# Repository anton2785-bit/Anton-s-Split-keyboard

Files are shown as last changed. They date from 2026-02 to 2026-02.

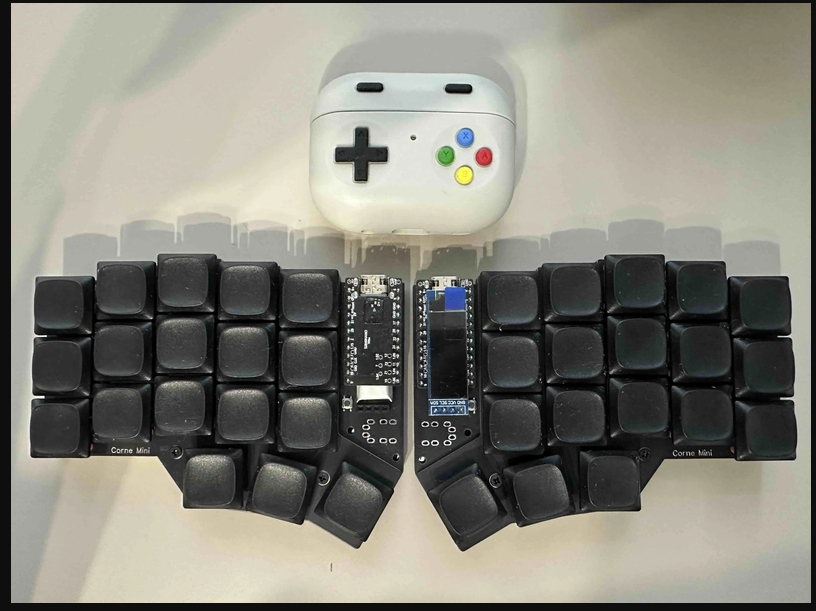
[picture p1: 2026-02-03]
Images/Inspiration image.png

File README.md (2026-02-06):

# Anton-s-Split-keyboard
---
# BOM
* 2x XIAO nRF52840 SMD ( the microcontrollers )
* 40x MX-Style switches ( preferably black or red)
* 40x Black keykaps
* 40x diodes
* 3x mini LEDs
* 2x Batteries
* 1x Rotary encoder
* The 2 difrent case parts
* The 2 PCBs
---
# Images
* This image inspired me for the layout for the keyboard
Inspiration image

* These are both sides of the keyboard in the shematic tab in kicad
Schematic PCB left side
Schematic PCB right side

* This is the final PCB wiring
PCB in PCB editor

* and the 3d models of it
3D model PCB 1
3D model PCB 2

* This is the case, that i made
3D model case

* And this is the whole assembly
3D model assembly

---
# Instructions of how to assemble
* First solder all of the diodes, keyboard switches, LEDs, Microcontrollers and batteries
* Second place the now assembled PCB in the case and connect it to a computer via USB C cable
* Third you need to upload the Firmware on the microcontrollers
* And finally you need to put all of the keycaps and test the keyboard

---
# Use Cases
- Expanding my hands-on experience with hardware by designing more advanced PCBs and practicing soldering.
- Challenging myself to improve typing speed and ergonomics by adapting to different keyboard layouts.

---
# Credits

Designed and built by (Anton/ Anton-2785-bit) Inspired by open‑source mechanical keyboard and hackpad communities (https://blueprint.hackclub.com/home).

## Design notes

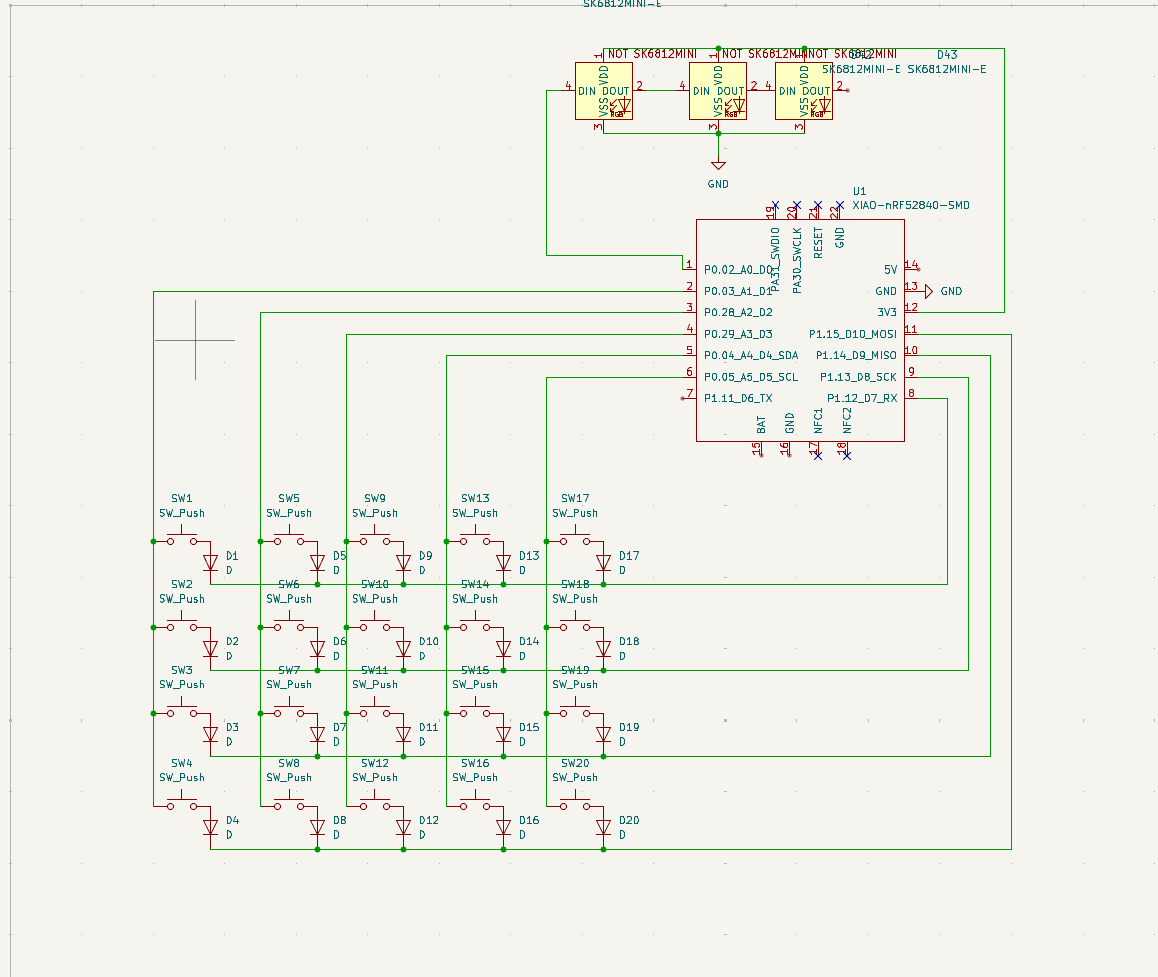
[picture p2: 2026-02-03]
Images/Schematic PCB left side.png

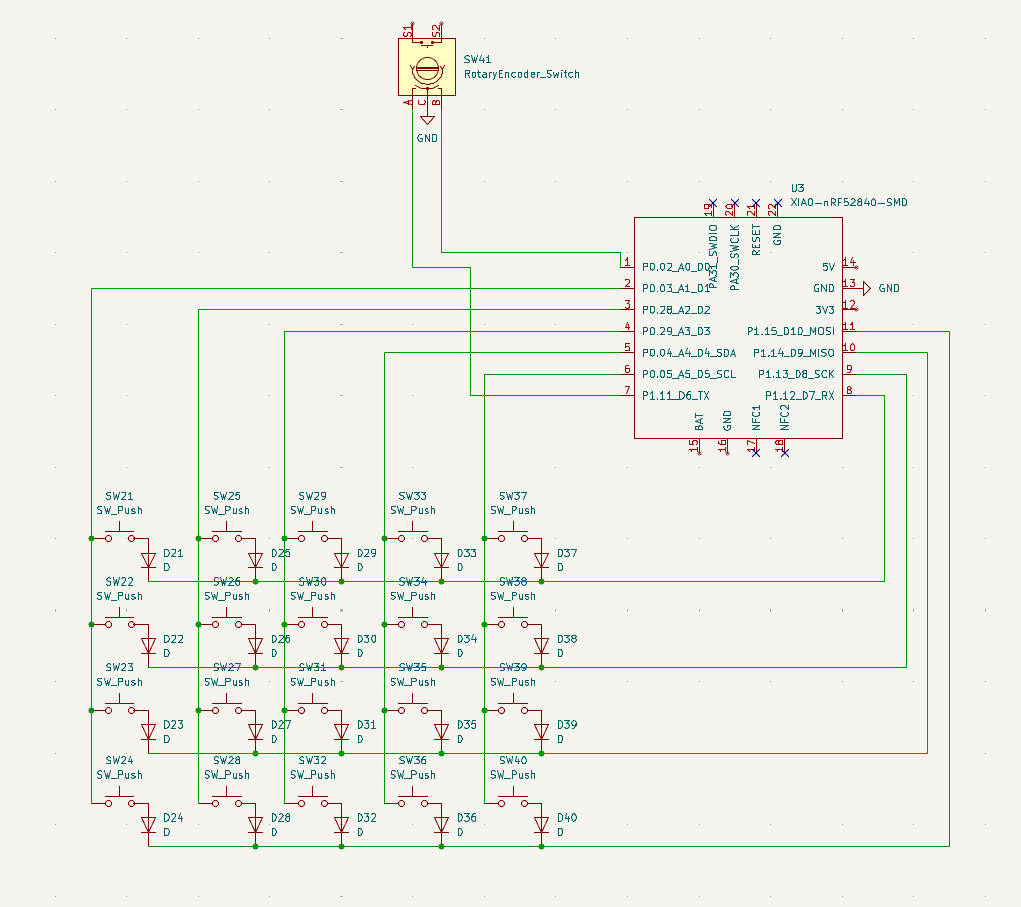
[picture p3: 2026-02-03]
Images/Schematic PCB right side.png

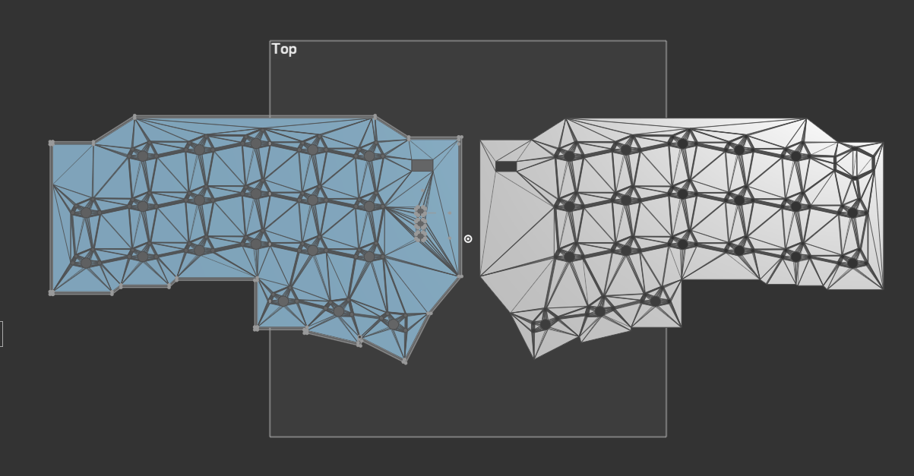
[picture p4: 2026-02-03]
Images/3D model PCB 1.png

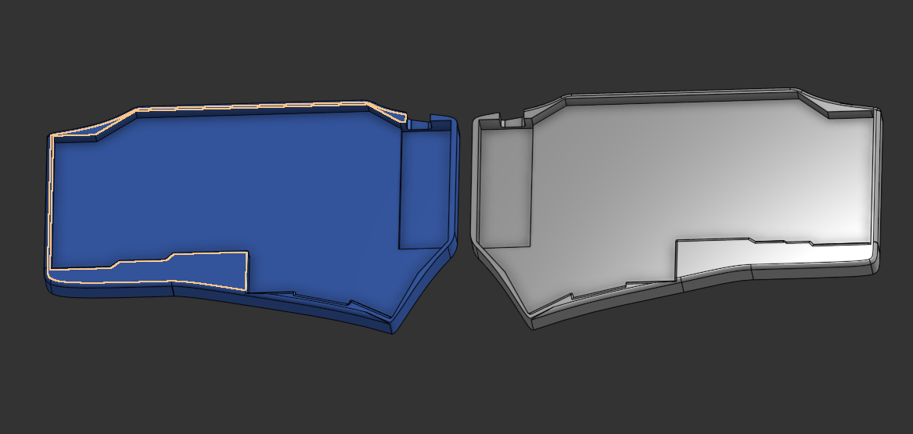
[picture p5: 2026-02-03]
Images/3D model case.png

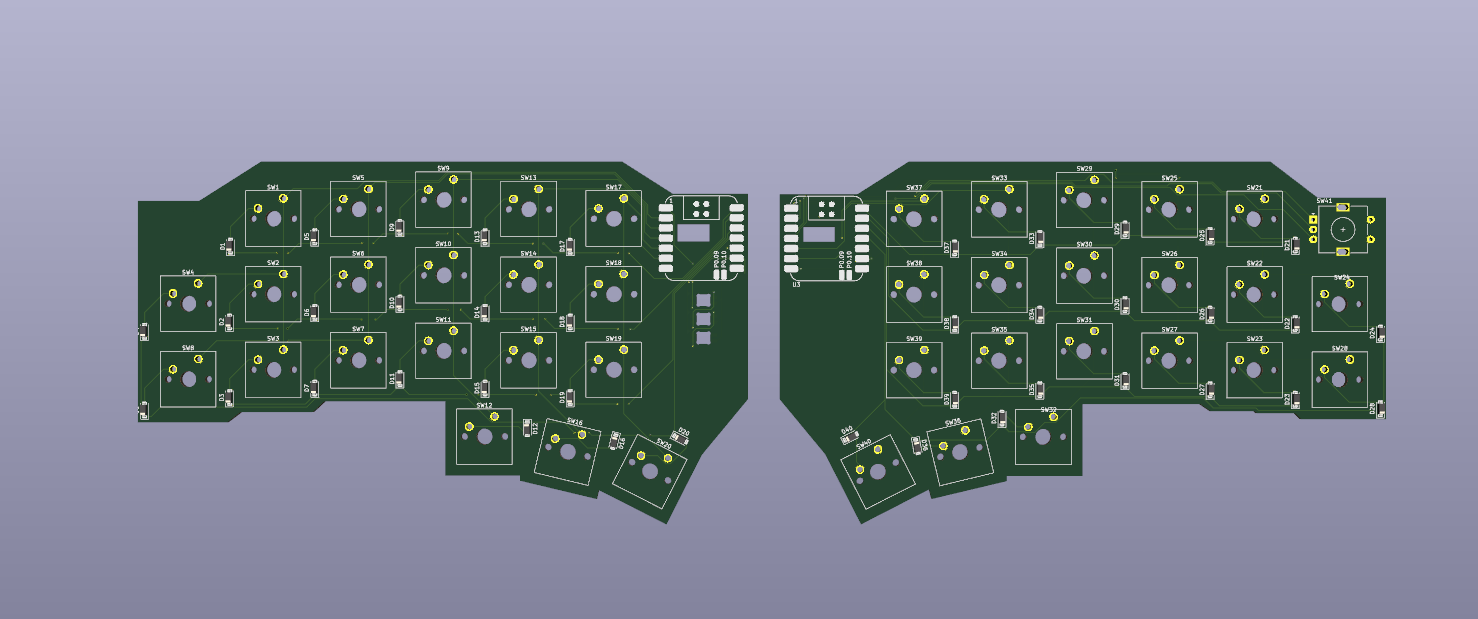
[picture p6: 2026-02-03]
Images/3D model PCB 2.png

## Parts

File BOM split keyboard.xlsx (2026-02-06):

Product name | Product description | Prodict link | Product unit needed | Product amount in listing | Product price euro | Product price USD
Seeed Studio XIAO nRF52840 | A microcontroller for each side | Seed Studio (https://www.seeedstudio.com/Seeed-XIAO-BLE-nRF52840-p-5201.html) | 2 | 2 | 17.89 | 19.80
Cherry MX Black Switch 5 Pins | Keyboard switches | Aliexpress (https://www.aliexpress.com/item/1005007588533637.html?mp=1) | 40 | 50 | 20.02 | 23.62
EC11 Encoder With Push Button | Rotary encoder for volume | Aliexpress (https://www.aliexpress.com/item/1005006111225091.html?curPageLogUid=G9LCGapRte49) | 1 | 2 | 2.74 | 3.23
3.7V 750mAh Battery | A battery for each side | Aliexpress (https://www.aliexpress.com/item/1005007138612313.html?curPageLogUid=ZzNXtTF9czc2) | 2 | 2 | 10.19 ( 0.86 with new shoppers save) | 12.03 or 1.01
Diodes 1N5819 SOD123 | Diodes | Aliexpress (https://www.aliexpress.com/item/1005010373909049.html?mp=1) | 40 | 100 | 2.13 | 2.51
SK6812 MINI-E RGB | Mini LEDs for showing layout number | Aliexpress (https://www.aliexpress.com/item/1005008591589739.html?curPageLogUid=bhxoNd0DLbsU) | 3 | 100 | 3.56 | 4.20
Blank black keycaps | Keycaps for the switches | Aliexpress (https://www.aliexpress.com/item/1005005305167568.html?mp=1) | 40 | 20 | 11.16 | 13.17
Left side PCB | The PCB for the left side | image bellow | 5 | 1 | 8.04 | 9.49
Right side PCB | The PCB for the right side | image bellow | 5 | 1 | 8.04 | 9.49
 |  |  |  |  | Price without new shopers save | 97.54
 |  |  |  |  | Price with new shopers save | 86.52
 |  |  |  |  | Shipping from aliexpress - 2.27 euro | 2.68
 |  |  |  |  | Shipping from seed studio - 8.24 euro | 9.72
 |  |  |  |  | Shipping from JLCPCB | 7

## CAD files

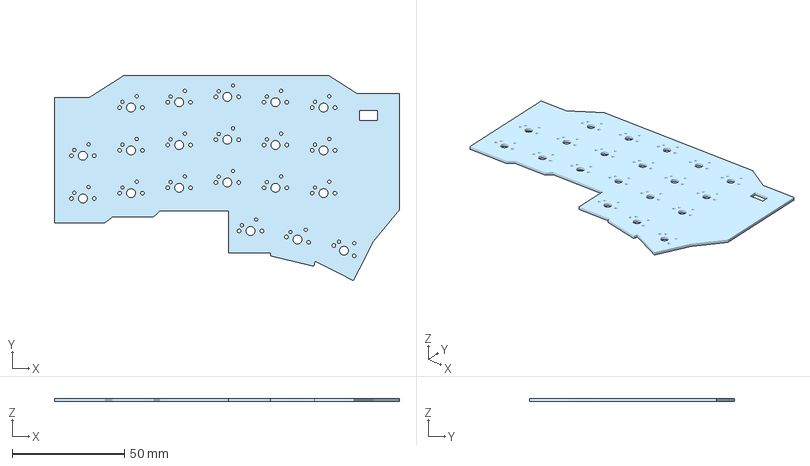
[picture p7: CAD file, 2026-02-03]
CAD/PCB left.step
153.6 x 91.4 x 1.51 mm

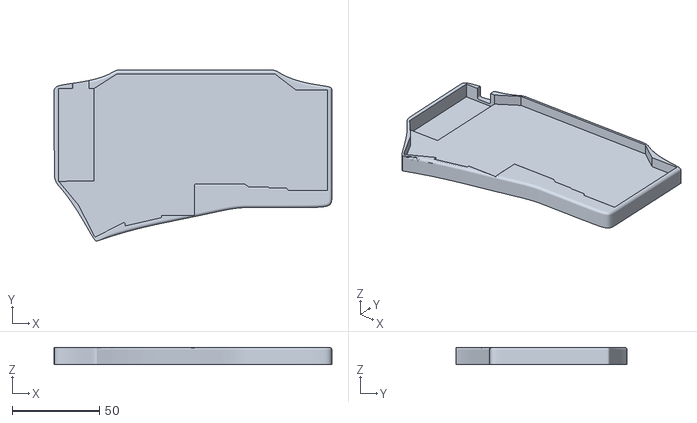
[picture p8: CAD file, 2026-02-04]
Production/Right case.stl
159.7 x 98.5 x 10.0

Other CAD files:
CAD/PCB right.step
Production/Left case.stl
CAD/Case left.step
CAD/Case right.step

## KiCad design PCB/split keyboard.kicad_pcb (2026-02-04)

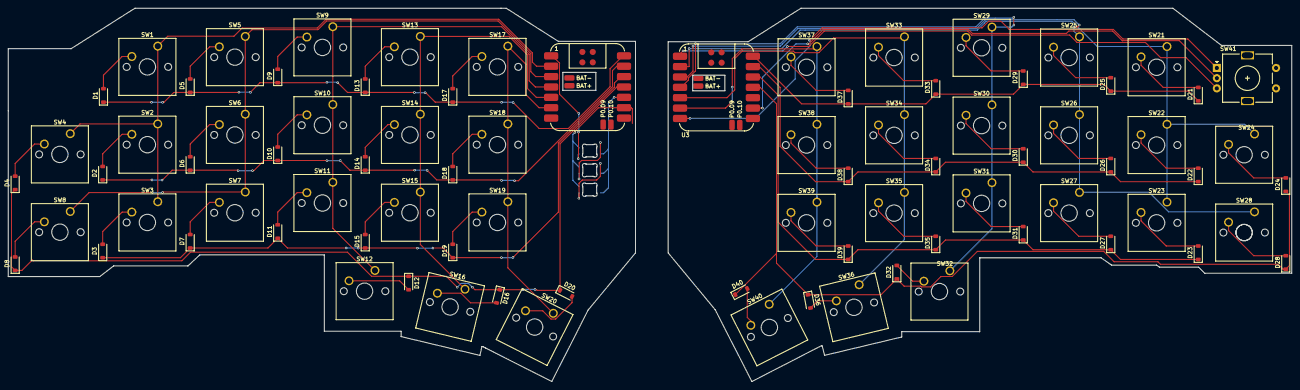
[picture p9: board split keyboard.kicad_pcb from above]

Board: 2 copper layers, 314.3 x 91.4 mm, 86 parts (0 on the bottom side), 65 nets.

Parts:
D1, D2, D3, D4, D5, D6, D7, D8, D9, D10, D11, D12, D13, D14, D15, D16, D17, D18, D19, D20, D21, D22, D23, D24, D25, D26, D27, D28, D29, D30, D31, D32, D33, D34, D35, D36, D37, D38, D39, D40: D; D_SOD-123
D41, D42, D43: SK6812MINI-E; MX_SK6812MINI-E_REV
SW1, SW2, SW3, SW4, SW5, SW6, SW7, SW8, SW9, SW10, SW11, SW12, SW13, SW14, SW15, SW16, SW17, SW18, SW19, SW20, SW21, SW22, SW23, SW24, SW25, SW26, SW27, SW28, SW29, SW30, SW31, SW32, SW33, SW34, SW35, SW36, SW37, SW38, SW39, SW40: SW_Push; SW_Cherry_MX_1.00u_PCB
SW41: RotaryEncoder_Switch; RotaryEncoder_Alps_EC11E-Switch_Vertical_H20mm
U1, U3: XIAO-nRF52840-SMD; Xiao_nRF52840_AC_Reflow

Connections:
GND: D41.3 (VSS), D42.3 (VSS), D43.3 (VSS), SW41.C, U1.13 (GND), U3.13 (GND)
unnamed: D1.2 (A), SW1.2
unnamed: D1.1 (K), D5.1 (K), D9.1 (K), D13.1 (K), D17.1 (K), U1.8 (P1.12_D7_RX)
unnamed: D2.2 (A), SW2.2
unnamed: D3.2 (A), SW3.2
unnamed: D4.2 (A), SW4.2
unnamed: D5.2 (A), SW5.2
unnamed: D6.2 (A), SW6.2
unnamed: D7.2 (A), SW7.2
unnamed: D8.2 (A), SW8.2
unnamed: D9.2 (A), SW9.2
unnamed: D10.2 (A), SW10.2
unnamed: D2.1 (K), D6.1 (K), D10.1 (K), D14.1 (K), D18.1 (K), U1.9 (P1.13_D8_SCK)
unnamed: D11.2 (A), SW11.2
unnamed: D3.1 (K), D7.1 (K), D11.1 (K), D15.1 (K), D19.1 (K), U1.10 (P1.14_D9_MISO)
unnamed: D12.2 (A), SW12.2
unnamed: D4.1 (K), D8.1 (K), D12.1 (K), D16.1 (K), D20.1 (K), U1.11 (P1.15_D10_MOSI)
unnamed: D13.2 (A), SW13.2
unnamed: D14.2 (A), SW14.2
unnamed: D15.2 (A), SW15.2
unnamed: D16.2 (A), SW16.2
unnamed: D17.2 (A), SW17.2
unnamed: D18.2 (A), SW18.2
unnamed: D19.2 (A), SW19.2
unnamed: D20.2 (A), SW20.2
unnamed: D21.2 (A), SW21.2
unnamed: D21.1 (K), D25.1 (K), D29.1 (K), D33.1 (K), D37.1 (K), U3.8 (P1.12_D7_RX)
unnamed: D22.2 (A), SW22.2
unnamed: D22.1 (K), D26.1 (K), D30.1 (K), D34.1 (K), D38.1 (K), U3.9 (P1.13_D8_SCK)
unnamed: D23.2 (A), SW23.2
unnamed: D23.1 (K), D27.1 (K), D31.1 (K), D35.1 (K), D39.1 (K), U3.10 (P1.14_D9_MISO)
unnamed: D24.2 (A), SW24.2
unnamed: D24.1 (K), D28.1 (K), D32.1 (K), D36.1 (K), D40.1 (K), U3.11 (P1.15_D10_MOSI)
unnamed: D25.2 (A), SW25.2
unnamed: D26.2 (A), SW26.2
unnamed: D27.2 (A), SW27.2
unnamed: D28.2 (A), SW28.2
unnamed: D29.2 (A), SW29.2
unnamed: D30.2 (A), SW30.2
unnamed: D31.2 (A), SW31.2
unnamed: D32.2 (A), SW32.2
unnamed: D33.2 (A), SW33.2
unnamed: D34.2 (A), SW34.2
unnamed: D35.2 (A), SW35.2
unnamed: D36.2 (A), SW36.2
unnamed: D37.2 (A), SW37.2
unnamed: D38.2 (A), SW38.2
unnamed: D39.2 (A), SW39.2
unnamed: D40.2 (A), SW40.2
unnamed: D41.4 (DIN), U1.1 (P0.02_A0_D0)
unnamed: D41.2 (DOUT), D42.4 (DIN)
unnamed: D41.1 (VDD), D42.1 (VDD), D43.1 (VDD), U1.12 (3V3)
unnamed: D42.2 (DOUT), D43.4 (DIN)
unnamed: SW1.1, SW2.1, SW3.1, SW4.1, U1.2 (P0.03_A1_D1)
unnamed: SW13.1, SW14.1, SW15.1, SW16.1, U1.5 (P0.04_A4_D4_SDA)
unnamed: SW17.1, SW18.1, SW19.1, SW20.1, U1.6 (P0.05_A5_D5_SCL)
unnamed: SW5.1, SW6.1, SW7.1, SW8.1, U1.3 (P0.28_A2_D2)
unnamed: SW9.1, SW10.1, SW11.1, SW12.1, U1.4 (P0.29_A3_D3)
unnamed: SW41.B, U3.1 (P0.02_A0_D0)
unnamed: SW21.1, SW22.1, SW23.1, SW24.1, U3.2 (P0.03_A1_D1)
unnamed: SW33.1, SW34.1, SW35.1, SW36.1, U3.5 (P0.04_A4_D4_SDA)
unnamed: SW37.1, SW38.1, SW39.1, SW40.1, U3.6 (P0.05_A5_D5_SCL)
unnamed: SW25.1, SW26.1, SW27.1, SW28.1, U3.3 (P0.28_A2_D2)
unnamed: SW29.1, SW30.1, SW31.1, SW32.1, U3.4 (P0.29_A3_D3)
unnamed: SW41.A, U3.7 (P1.11_D6_TX)

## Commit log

2026-02-04 File update
    [Case left.step, Case right.step, Left case.stl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]
2026-02-04 Update README with images and descriptions
    Added images and descriptions for keyboard layout, PCB schematics, wiring, and assembly.
2026-02-04 Update README with use cases and credits
    Added a use case section and updated credits.
